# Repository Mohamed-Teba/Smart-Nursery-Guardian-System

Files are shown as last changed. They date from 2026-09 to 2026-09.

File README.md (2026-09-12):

# 🍼 Smart Nursery Guardian System

<p align="center">
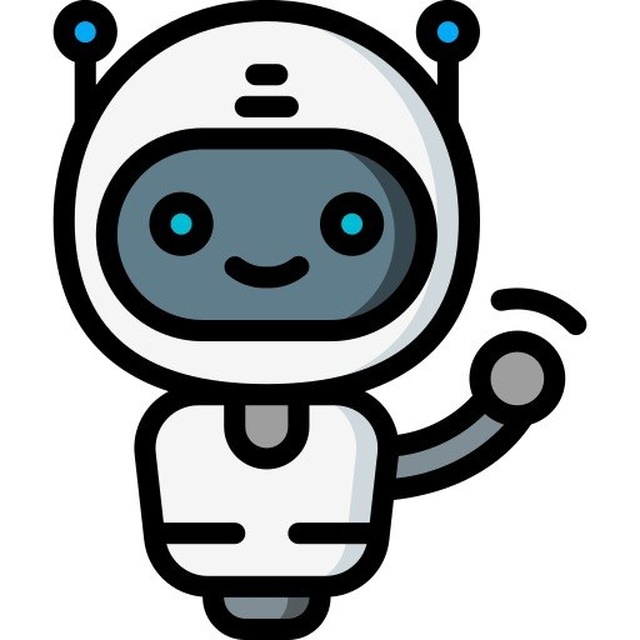
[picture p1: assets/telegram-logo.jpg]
Smart Nursery Guardian Logo
  
</p>

<p align="center">
  <strong>An intelligent IoT + Machine Learning system that monitors a baby’s environment, detects cry reasons, and alerts caregivers in real time.</strong>
</p>

<p align="center">
  
  
  
  
  
  
</p>

---

## 👥 Team 6 Members

| Name | ID |
|---|---|
| Mohamed Ibrahim | 7131E  |
| Pilopateer Hani | 7129E  |
| Tharaa Mohamed | 7005E  |

---

## 📖 Project Overview

**Smart Nursery Guardian** is a complete end-to-end smart baby monitoring system that combines:

- **Hardware sensors** (temperature, gas/smoke, light, motion)
- **Actuators** (fan, RGB LED, room lamp, servo rocker, buzzer)
- **Machine Learning** cry classification (Hungry / Tired / Discomfort)
- **Real-time dashboard** (Streamlit)
- **Instant caregiver alerts** via Telegram Bot

The system continuously monitors the nursery environment. When the baby cries, an audio clip is analyzed by a trained ML model. The predicted reason is sent to the Arduino, which activates the appropriate actuators, updates the LCD, and triggers a Telegram notification to the parents.

---

## ✨ Key Features

### 🔊 Cry Classification (ML)
- Detects three cry types: **Hungry**, **Tired**, **Discomfort**
- Feature extraction using Librosa (MFCC, spectral features, RMS, ZCR, etc.)
- Trained on the Donate-a-Cry corpus features dataset
- Real-time prediction from uploaded audio or live microphone

### 🌡️ Environmental Monitoring
- Temperature sensing + automatic fan speed control (Low / Half / Full)
- Gas / Smoke detection with emergency alert
- Light (LDR) sensing for automatic night lamp
- PIR motion detection to determine if baby is awake or sleeping

### 🤖 Smart Actuators
- **Servo motor** rocks the bed when baby is crying or awake
- **Buzzer** activates on Tired cry or Gas alert
- **RGB LED** indicates temperature status
- **Room lamp** turns on automatically in dark conditions when baby is active

### 📱 Caregiver Notifications
- Telegram Bot (`@SMART_NURSERY_GUARDIAN_bot`) sends instant alerts:
  - Cry reason + confidence
  - Gas / Smoke emergency

### 🖥️ Live Dashboard
- Beautiful dark-themed Streamlit interface
- Real-time metrics (Temp, Motion, Gas, Lamp)
- Serial log, ML info, mock testing buttons
- Manual audio upload for prediction

---

## 🖼️ System Screenshots

### Dashboard – Temp Alert
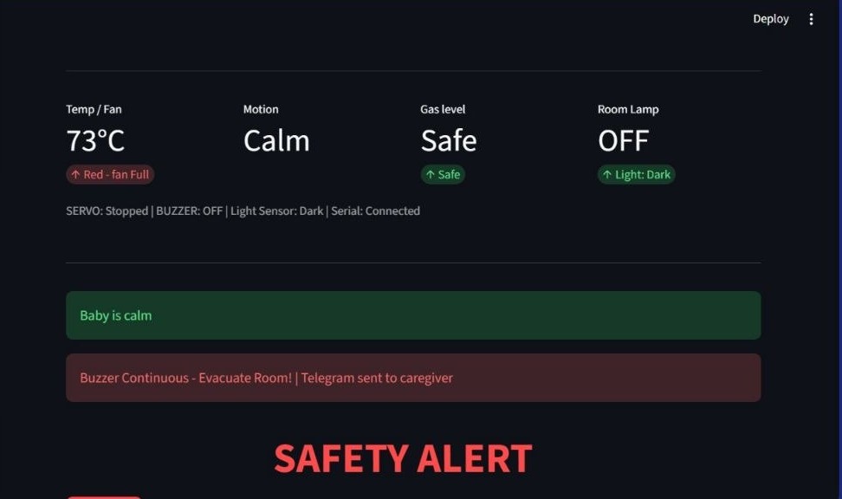
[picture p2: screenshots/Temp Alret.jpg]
Temp Alert Dashboard


### Dashboard – Gas Alert
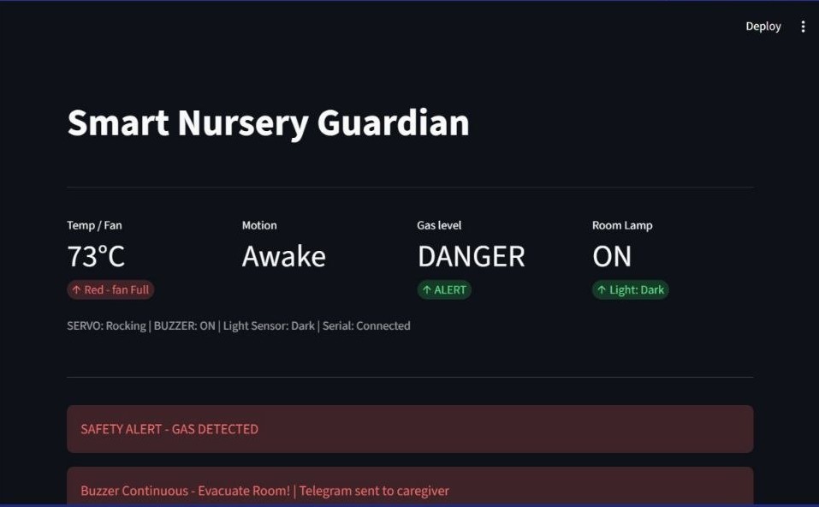
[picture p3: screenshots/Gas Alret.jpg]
Gas Alert Dashboard


### Hardware LCD Display
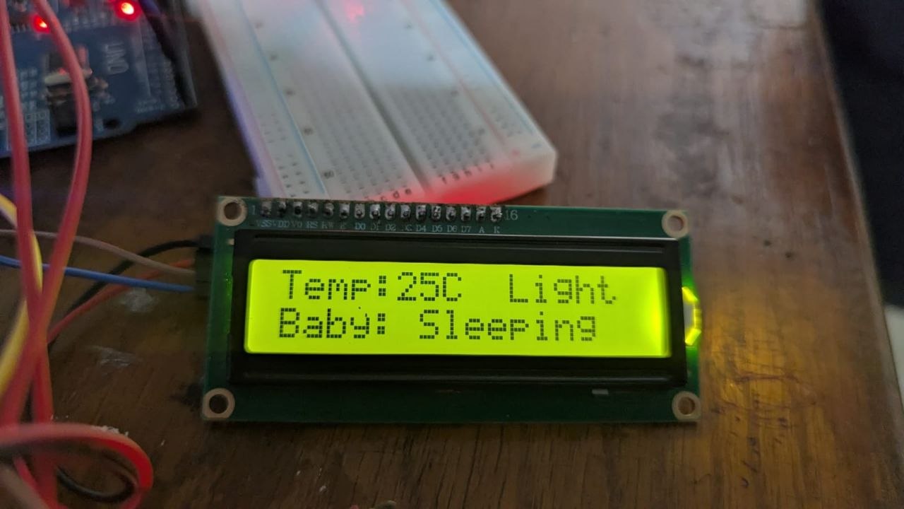
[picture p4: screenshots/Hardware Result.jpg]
Hardware LCD


### Telegram Bot
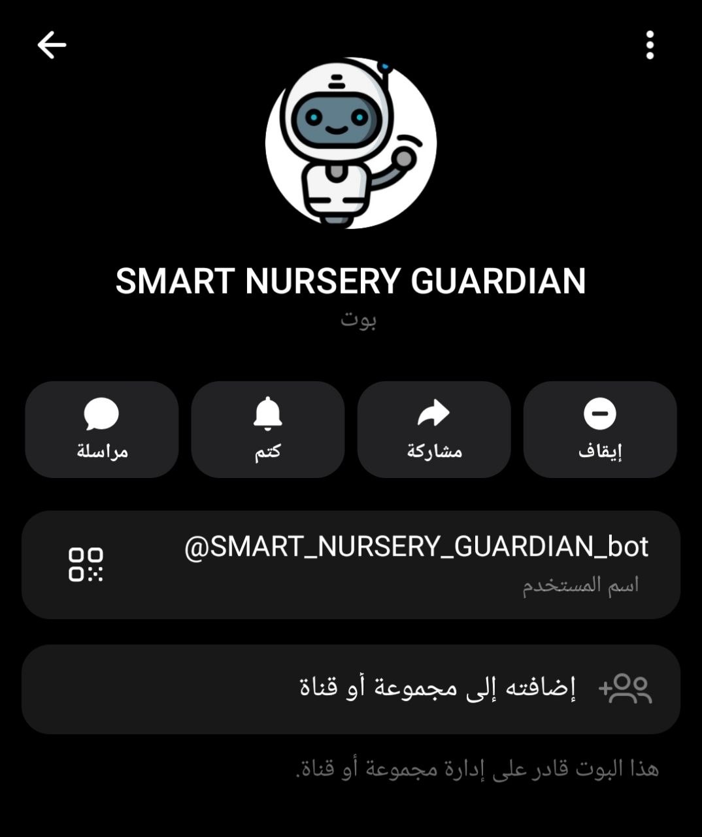
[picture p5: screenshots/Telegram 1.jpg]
Telegram Bot


---

## 🔌 Hardware Design

### Full Circuit Diagram
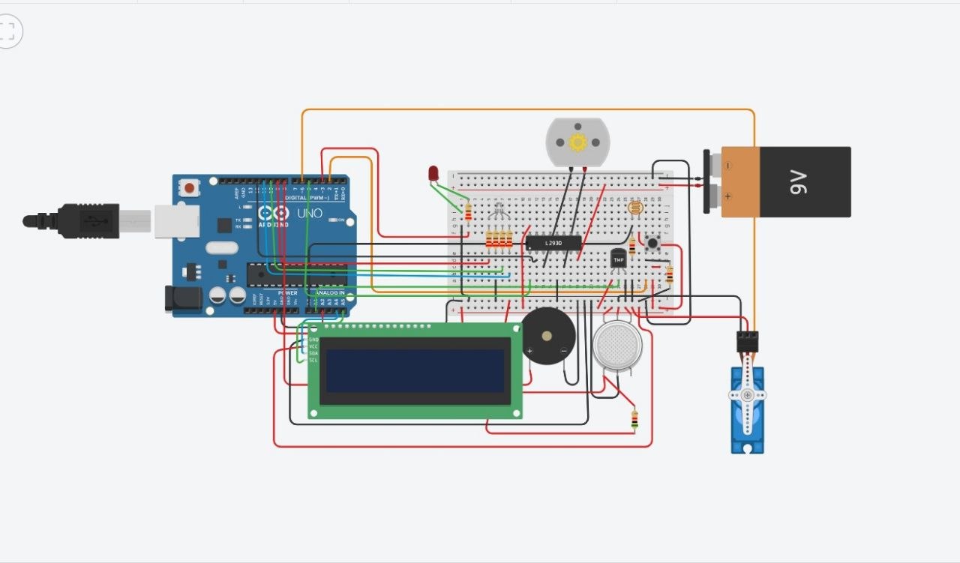
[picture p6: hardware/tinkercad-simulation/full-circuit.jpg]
Full Circuit


### Custom PCB (3D View)
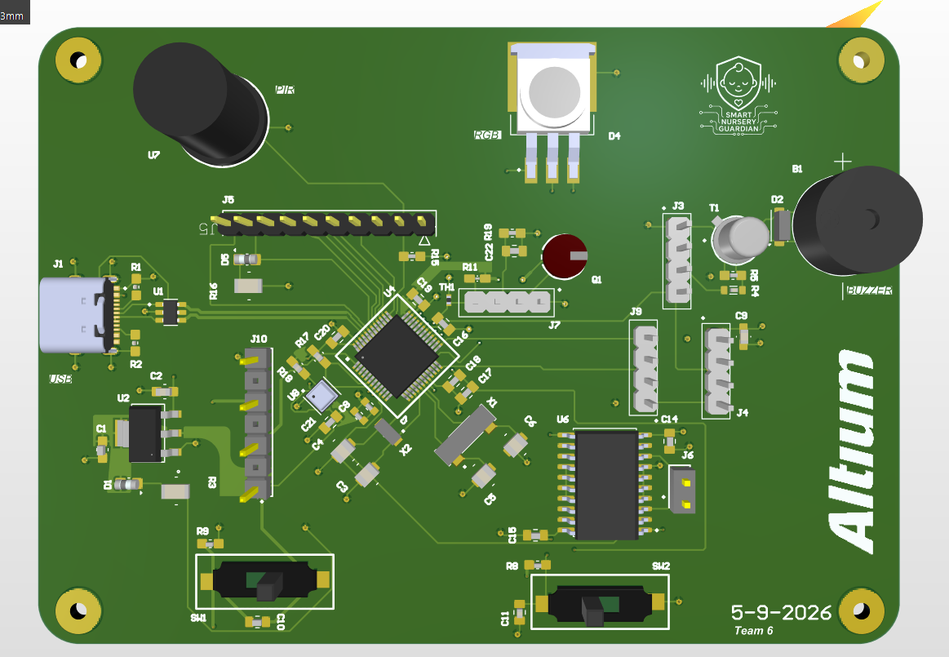
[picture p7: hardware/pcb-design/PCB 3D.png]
PCB 3D


> Designed in **Altium Designer** – dated 5-9-2026 – Team 6

### Main Components

| Component | Purpose | Pin / Connection |
|---|---|---|
| Arduino Uno | Main controller | - |
| LCD 16x2 (I2C) | Status display | SDA/SCL |
| PIR Motion Sensor | Detect baby movement | Digital 2 |
| LDR | Light intensity | Analog A0 |
| Temperature Sensor | Ambient temperature | Analog A1 |
| MQ Gas Sensor | Smoke / Gas detection | Analog A2 |
| Servo Motor | Rock the baby bed | Digital 6 |
| Buzzer | Audio alerts | Digital 8 |
| RGB LED | Temperature status indication | 9, 10, 11 |
| DC Fan + L293D | Cooling system | PWM 5 + Direction 12  |
| Room LED | Night lamp | Digital 3 |
| 9V Battery | External power for motor driver | - |

---

## 🧠 Machine Learning Pipeline

The model was trained on the **Donate-a-Cry Corpus Features Dataset**.

**Classes:**
- `hungry`
- `tired`
- `discomfort`

**Pipeline steps:**
1. Robust imputation + scaling
2. Feature selection (`SelectKBest`)
3. Class balancing (SMOTE / RandomOverSampler)
4. Model comparison (Logistic Regression, SVM, Random Forest, Extra Trees, HistGradientBoosting, KNN)
5. Hyperparameter tuning with `RandomizedSearchCV`
6. Final best model saved as `smart-nursery-guardian-model.pkl`

**Feature set (must match exactly at inference):**
- Amplitude_Envelope_Mean, RMS_Mean, ZCR_Mean, STFT_Mean
- SC_Mean, SBAN_Mean, SCON_Mean
- MFCCs13Mean, delMFCCs13, del2MFCCs13, MelSpec, MFCCs20
- MFCCs1 … MFCCs13

> See `machine-learning-pipeline.ipynb` for the complete training notebook.

---

## 🛠️ Software Architecture

```
┌─────────────────────┐       Serial (9600)      ┌─────────────────────┐
│  Streamlit Dashboard│ ◄──────────────────────► │   Arduino Firmware  │
│  (app.py)           │                          │   (main.ino)        │
│                     │                          │                     │
│  • ML Inference     │                          │  • Sensors reading  │
│  • Telegram Alerts  │                          │  • Actuator control │
│  • Live Metrics     │                          │  • LCD updates      │
│  • Serial Bridge    │                          │  • Command ACK      │
└─────────────────────┘                          └─────────────────────┘
```

**Communication Protocol**

| Direction | Message Example | Meaning |
|---|---|---|
| Laptop → Micro  | `CRY:hungry` | Activate hungry cry response |
| Laptop → Micro  | `CRY:tired` | Activate tired cry + buzzer |
| Laptop → Micro  | `CRY:discomfort` | Activate discomfort response |
| Laptop → Micro  | `RESET` | Return to calm state |
| Micro → Laptop  | `GAS:450` | Gas sensor value |
| Micro → Laptop  | `TEMP:28` | Temperature reading |
| Micro → Laptop  | `LIGHT:DARK` / `BRIGHT` | Light condition |
| Micro → Laptop  | `AWAKE` / `MOTION:3` | Motion / awake status |
| Micro → Laptop  | `ALERT:GAS_DETECTED` | Emergency gas alert |
| Micro → Laptop  | `ACK:CRY:Hungry` | Command acknowledgment |

---

## 🚀 Getting Started

### 1. Hardware Setup
1. Wire the circuit according to the diagram above (or use the custom PCB).
2. Upload `main.ino` to the Arduino Uno using the Arduino IDE.
3. Connect the Arduino to the laptop via USB.

### 2. Software Setup

```bash
# Clone the repository
git clone https://github.com/YOUR_USERNAME/smart-nursery-guardian.git
cd smart-nursery-guardian

# Create virtual environment (recommended)
python -m venv venv
source venv/bin/activate          # Windows: venv\Scripts\activate

# Install dependencies
pip install -r requirements.txt
```

**Required packages** (suggested `requirements.txt`):
```
streamlit
pyserial
joblib
numpy
pandas
scikit-learn
imbalanced-learn
librosa
sounddevice
soundfile
python-telegram-bot
```

### 3. Model Placement
Place the trained model file at:
```
model/smart-nursery-guardian-model.pkl
```

### 4. Telegram Configuration
Create a `.streamlit/secrets.toml` file:
```toml
Token = "YOUR_TELEGRAM_BOT_TOKEN"
chat_id = "YOUR_CHAT_ID"
```

### 5. Run the Dashboard
```bash
streamlit run app.py
```

---

## 🎮 How to Use

1. Open the Streamlit dashboard.
2. Enter the correct **COM Port** (e.g. `COM7` on Windows or `/dev/ttyUSB0` on Linux).
3. Click **Start Monitoring**.
4. Use the **Mock Tests** buttons to simulate cry types and gas alerts.
5. Upload a real cry audio file (WAV/MP3) and click **Predict Uploaded File**.
6. Watch the dashboard, LCD, actuators, and Telegram notifications update in real time.
7. Click **Reset** to return the system to calm state.

---

## 📁 Repository Structure

```
smart-nursery-guardian/
├── app.py                          # Streamlit dashboard + serial + ML + Telegram
├── main.ino                        # Arduino firmware
├── machine-learning-pipeline.ipynb # Full ML training notebook
├── model/
│   └── smart-nursery-guardian-model.pkl
├── assets/
│   ├── full-circuit.jpg
│   ├── PCB 3D.png
│   ├── Hardware Result.jpg
│   ├── Gas Alret.jpg
│   ├── Temp Alret.jpg
│   ├── Telegram 1.jpg
│   └── logo.png                    # (add your logo here)
├── requirements.txt
└── README.md
```

---

## 🔮 Future Improvements

- Continuous live microphone monitoring with background thread
- Edge deployment of the ML model on a Raspberry Pi / ESP32
- Mobile companion app
- Multi-baby support
- Historical data logging & analytics dashboard
- Better noise-robust cry detection

---

## 📄 License

This project was developed as an academic graduation / course project by **Team 6**.  
Feel free to use and modify it for educational purposes.

---

<p align="center">
  <strong>Made with ❤️ by Team 6 – Smart Nursery Guardian</strong><br>
  Protecting little ones with technology.
</p>

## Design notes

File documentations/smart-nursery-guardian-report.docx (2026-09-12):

SMART NURSERY GUARDIAN

An AI-Assisted Embedded Monitoring System for Infant Care

Final Project Report

Team 6

Name | ID | Role
Mohamed Ibrahim | 7131E | Machine Learning / Audio Pipeline / GUI / Telegram
Filopateer Hani | 7129E | Hardware / Serial Integration
Tharaa Mohamed | 7005E | PCB / Firmware

An intelligent crib-side system that listens to infant cries, classifies the cause

using machine learning, and automatically soothes the baby while notifying caregivers.

# Table of Contents:

1. Introduction ------------------------------------------------------------------------------------------------ 3

2. Project Objectives --------------------------------------------------------------------------------------- 3

3. System Overview & Architecture -------------------------------------------------------------------- 4

4. Hardware Design ----------------------------------------------------------------------------------------- 4

5. Software Design ------------------------------------------------------------------------------------------ 6

5.1 Streamlit Dashboard (Laptop)

5.2 Arduino Firmware (Microcontroller)

5.3 Serial Communication Protocol

6. Machine Learning Pipeline ----------------------------------------------------------------------------- 8

7. System Workflow (End-to-End) ----------------------------------------------------------------------- 9

8. Implementation Details & Screenshots ------------------------------------------------------------- 9

9. Testing & Results --------------------------------------------------------------------------------------- 11

10. Challenges & Solutions ------------------------------------------------------------------------------- 11

11. Conclusion ----------------------------------------------------------------------------------------------- 12

12. Future Work ----------------------------------------------------------------------------------------------12

13. Resources & References ----------------------------------------------------------------------------- 12

# 1. Introduction:

At 3 a.m., a baby cries. Is she hungry? Tired? In discomfort? The parent stands in darkness guessing. Crying is the infant’s only language, and most parents cannot read it fluently. Sleep deprivation, anxiety, and delayed responses are common consequences.

Smart Nursery Guardian is an AI-assisted embedded monitoring system that listens to the cry, uses a trained machine-learning model to identify the cause (hungry, tired, or discomfort), and reacts instantly: rocking the crib, displaying a clear message on an LCD and a modern GUI, sounding a buzzer when needed, and sending a Telegram alert to the caregiver’s phone. Nearby sensors continuously monitor motion, light level, air quality, and temperature, controlling lights and cooling automatically.

The system aims to respond as fast and attentively as a caregiver watching the crib — but never sleeps and never misses a signal.

## 1.1 Why This Project Matters

- Addresses a real, universal problem: sleep loss and stress caused by misinterpreting infant cries.
- Demonstrates a realistic technical stack: signal processing, classical ML, real-time firmware, GUI design, serial IoT communication, and cloud messaging.
- Bridges the gap between academic prototypes and practical home-use systems.

# 2. Project Objectives:

# | Objective | Success Criterion

1 | Classify infant cries into 3 clinically meaningful classes | Macro-F1 ≥ 0.75 on held-out test set
2 | Provide real-time visual & audible feedback | LCD + Streamlit GUI update < 1 s after prediction
3 | Automatically soothe the baby | Servo rocks continuously while cry is active
4 | Detect dangerous gas / smoke | Buzzer + Telegram alert within 2 s of threshold breach
5 | Maintain comfortable environment | Fan & RGB LED respond to temperature bands
6 | Notify caregiver remotely | Telegram message delivered for every cry & gas event

Cry Class | System Response | Priority
Hungry | Display message on GUI/LCD and play a calming video clip | Normal
Tired | Sound the buzzer immediately and display a warning (urgent pattern) | High
Discomfort | Display message and suggest checking diaper / clothing / position | Normal

# 3. System Overview & Architecture:

Two programs run on two devices and communicate over a serial (USB) link:

Component | Runs On | Main Responsibilities
Python / Streamlit App | Laptop | Microphone capture, feature extraction, ML inference, GUI dashboard, Telegram alerts, serial command & telemetry
Arduino Firmware | Microcontroller | Read PIR, LDR, thermistor, gas sensor; control servo, buzzer, room LED, RGB status LEDs, cooling fan; send sensor telemetry

## 3.1 Critical Data Paths

- Audio path (zero latency): Laptop microphone → Python feature extractor → trained model. Audio never crosses the serial link.
- Sensor path: Microcontroller reads sensors and streams values (GAS, TEMP, LIGHT, MOTION) to the laptop every second. Commands (CRY:hungry, RESET …) travel in the opposite direction.

This asymmetry is intentional: cry detection has the lowest possible latency, while environmental sensors can tolerate a short serial delay.

# 4. Hardware Design:

## 4.1 Bill of Materials & Pin Mapping

Component | Arduino Pin | Function
PIR Motion Sensor | D2 | Detect baby movement (awake detection)
LDR (Light Sensor) | A0 | Room darkness threshold
Thermistor (Temp) | A1 | Ambient temperature
MQ-series Gas Sensor | A2 | Smoke / gas detection
Room LED (Lamp) | D3 | Night light when dark + awake/cry
RGB LED – Red | D9 | Hot temperature indicator
RGB LED – Green | D10 | Comfortable temperature
RGB LED – Blue | D11 | Cold temperature
Cooling Fan (PWM) | D5 | Speed controlled by temperature
Fan Direction (IN) | D12 | Motor driver enable
Buzzer | D8 | Gas alert or tired-cry continuous tone
Servo Motor | D6 | Crib rocking (0° ↔ 90° ↔ 180°)
LCD 16×2 (I2C) | 0x27 | Local status display

## 4.2 Key Thresholds & Control Logic

Parameter | Value | Action
Darkness (LDR) | < 900 | Room considered dark
Gas / Smoke | > 400 | Buzzer ON + Telegram + GUI alert
Motion window | 8 seconds | Count PIR edges
Awake threshold | ≥ 4 motions | isBabyAwake = true
Temp < 25 °C | Blue LED | Fan low (PWM 100)
25–30 °C | Green LED | Fan half (PWM 160)
Temp > 30 °C | Red LED | Fan full (PWM 255)

## 4.3 Custom PCB Design

A custom 2-layer PCB was designed in Altium Designer (dated 5-9-2026, Team 6). The board integrates the microcontroller, sensor connectors, power regulation, servo and fan drivers, and the Smart Nursery Guardian logo.

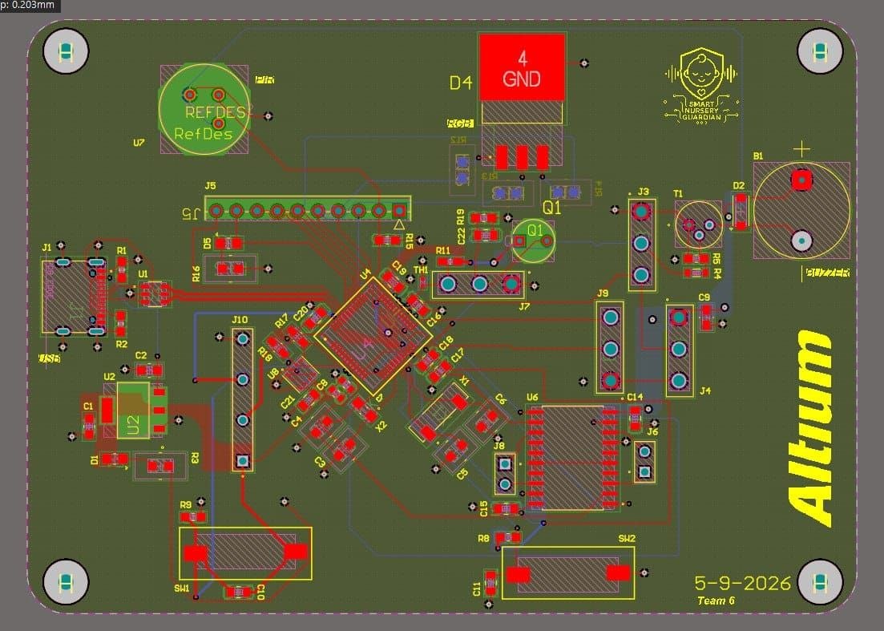
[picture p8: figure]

Figure 1 – PCB Layout (Altium Designer)

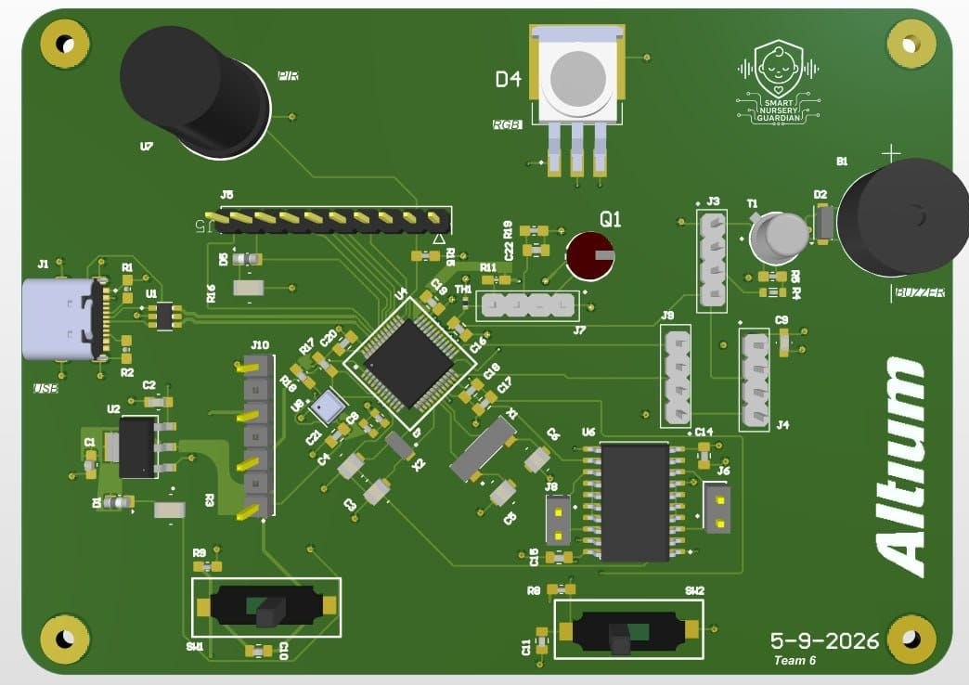
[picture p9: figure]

Figure 2 – 3D Render of the Assembled PCB

## 4.4 Hardware Prototype in Action


Figure 3 – Live LCD showing “Temp:25C Light / Baby: Sleeping” with surrounding sensors and wiring

5. Software Design:

## 5.1 Streamlit Dashboard (Laptop Side)

The caregiver interface is a responsive Streamlit web application that runs on the laptop. It provides real-time status cards, a serial log, manual audio upload, mock-test buttons, and automatic microphone monitoring.

Main Features

- Live metrics: Temperature / Fan, Motion (Awake/Calm), Gas level, Room Lamp
- Cry classification results with confidence scores
- Auto-mode continuous microphone loop (optional)
- Manual upload of cry audio files (WAV, MP3, …)
- Telegram notifications for every cry and gas event

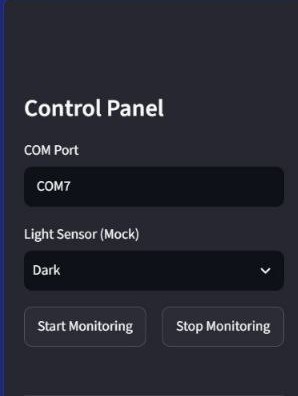
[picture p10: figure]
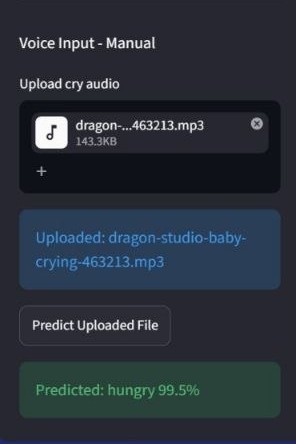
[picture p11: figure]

Figure 4 – Control Panel (COM Port & Start/Stop Monitoring) Figure 5 – Manual Voice Upload & Prediction Result (hungry 99.5%)

## 5.2 Arduino Firmware

The firmware (finalCodeHardware.ino) runs a tight non-blocking loop that:

- Reads serial commands from the laptop (CRY:hungry / tired / discomfort, RESET, …)
- Samples all sensors
- Updates the 8-second motion window and awake state
- Sends periodic telemetry (GAS, TEMP, LIGHT)
- Controls lighting, temperature actuators, buzzer, and servo rocking
- Refreshes the 16×2 LCD every 300 ms

## 5.3 Serial Communication Protocol

Direction | Message | Meaning
Laptop → MCU | CRY:hungry | Start hungry response (rock + display)
Laptop → MCU | CRY:tired | Start tired response (rock + continuous buzzer)
Laptop → MCU | CRY:discomfort | Start discomfort response
Laptop → MCU | RESET / CRY:END | Clear cry state, stop buzzer, center servo
MCU → Laptop | GAS:<value> | Raw gas sensor reading
MCU → Laptop | TEMP:<value> | Temperature in °C
MCU → Laptop | LIGHT:DARK/BRIGHT | Room light state
MCU → Laptop | MOTION:<n> | Motion count inside current window
MCU → Laptop | AWAKE | Baby declared awake (≥4 motions)
MCU → Laptop | ALERT:GAS_DETECTED | Gas threshold crossed
MCU → Laptop | ACK:… | Command acknowledgement

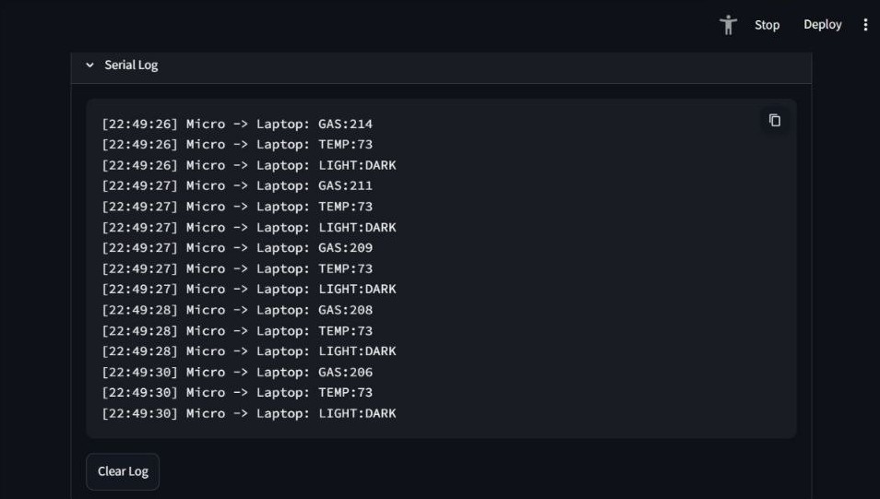
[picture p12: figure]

Figure 6 – Live Serial Log showing continuous GAS / TEMP / LIGHT telemetry

# 6. Machine Learning Pipeline:

## 6.1 Dataset

We used the publicly available Donate-a-Cry Corpus (457 labeled recordings). A pre-extracted feature version was obtained from Kaggle for rapid prototyping, while a matching feature-extraction routine was also implemented for live inference.

Class | Recordings | Percentage | System Response
Hungry | 382 | ≈ 84 % | Display message + optional calming video
Discomfort | 27 | ≈ 6 % | Display message (check diaper / position)
Tired | 24 | ≈ 5 % | Continuous buzzer + urgent warning

Note: The strong class imbalance is a well-known challenge of this dataset. SMOTE / RandomOverSampler inside the cross-validation pipeline and careful macro-F1 evaluation were used to mitigate it.

## 6.2 Feature Set (25 acoustic features)

Feature Group | Examples
Amplitude / Energy | Amplitude_Envelope_Mean, RMS_Mean
Temporal | ZCR_Mean
Spectral | STFT_Mean, SC_Mean, SBAN_Mean, SCON_Mean, MelSpec
MFCC | MFCCs13Mean, MFCCs1 … MFCCs13, MFCCs20
Delta MFCC | delMFCCs13, del2MFCCs13

## 6.3 Training Strategy

- 80 / 20 stratified train-test split (random_state = 42)
- 5-fold Stratified Cross-Validation inside the training set
- Pipeline: Imputer → Scaler → (optional) SMOTE → Classifier
- Models evaluated: Logistic Regression, SVM, Random Forest, Extra Trees, HistGradientBoosting, KNN, VotingClassifier
- Selection criterion: highest CV macro-F1 (balanced performance across the three classes)
- Final artifact saved as a single joblib file containing pipeline, feature names, class names

## 6.4 Live Inference Path

When a new audio file (or microphone buffer) arrives, the same feature-extraction recipe is applied, the resulting vector is fed to the loaded pipeline, and the predicted label plus confidence are returned. The GUI then issues the corresponding serial command and Telegram notification.

# 7. System Workflow (End-to-End):

## 7.1 Cry Detection & Classification

1. Laptop microphone (or uploaded file) captures audio.
1. Optional spectral noise reduction + voice-activity detection.
2. Fixed-length (5 s) feature vector is extracted.
3. Trained model returns one of {hungry, tired, discomfort} + confidence.
4. Streamlit updates status cards and log.
5. Serial command CRY:<label> is sent to the microcontroller.
6. Telegram message is dispatched to the caregiver.

## 7.2 Hardware Reaction

- Servo immediately begins a continuous rocking cycle (0° → 90° → 180°).
- LCD shows “Baby Crying! Reason: <label>”.
- If the label is tired, the buzzer stays on continuously.
- Room lamp turns on if the room is dark.

## 7.3 Environmental & Safety Loops

- PIR motion window (8 s) decides whether the baby is awake.
- Temperature band drives RGB LED colour and fan PWM.
- Gas sensor continuously compared against threshold 400; on breach the system enters the highest-priority SAFETY ALERT state (buzzer + full-screen GUI + Telegram).

# 8. Implementation Details & Screenshots

## 8.1 Gas Safety Alert (Highest Priority)


Figure 7 – GUI in SAFETY ALERT state: Gas = DANGER, Servo rocking, Buzzer ON, Telegram sent

## 8.2 Temperature / Calm State


Figure 8 – High temperature (73 °C in test) with Red-fan-Full indicator; baby calm

## 8.3 Telegram Bot Integration

A dedicated Telegram bot (@SMART_NURSERY_GUARDIAN_bot) receives every cry classification and every gas alert, giving the caregiver immediate mobile visibility even when away from the laptop. When gas is detected (or a cry is classified), the system sends a Telegram message to a pre-configured chat so the caregiver gets a phone alert even from another room. Implementation: a bot created through @BotFather provides the API token; the chat ID is read from the first getUpdates response; alerts are sent with python-telegram-bot — free, serverless, and far more reliable than browser-automation alternatives. Cry alerts are deduplicated per label and gas alerts are rate-limited to one message every 30 seconds to avoid notification spam.

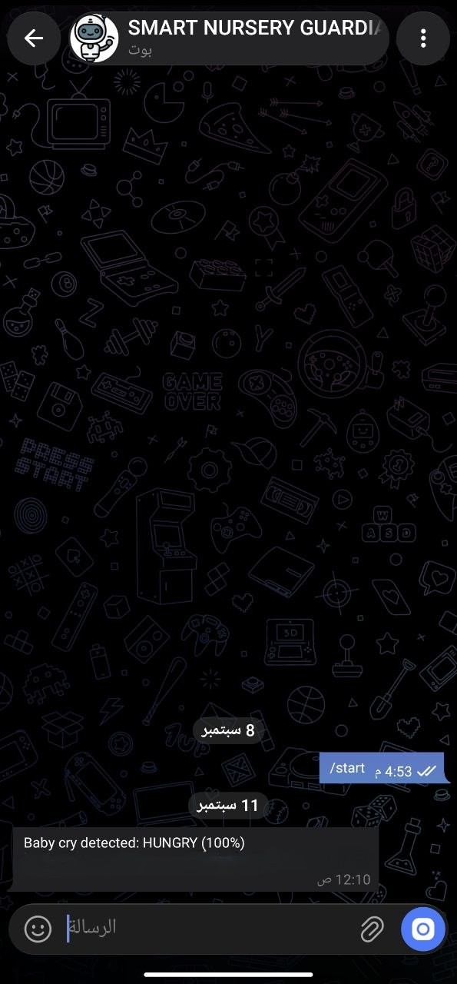
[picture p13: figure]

Figure 9 – Telegram bot profile Figure 10 – Real-time cry notification: “Baby cry detected: HUNGRY (100%)”

# 9. Testing & Results:

## 9.1 Functional Test Matrix

Test Case | Input / Stimulus | Expected Outcome | Result
Hungry cry (upload) | Audio file labelled hungry | GUI “hungry”, CRY:hungry, Telegram | Pass
Tired cry (mock) | Sidebar “Try Tired” | Continuous buzzer + LCD “Tired” | Pass
Discomfort cry | Sidebar “Try Discomfort” | LCD message + rock, no buzzer | Pass
Gas threshold | Sensor > 400 or mock button | Full SAFETY ALERT + Telegram | Pass
Motion → Awake | ≥ 4 PIR edges in 8 s | isBabyAwake, LCD “Awake” | Pass
Dark + Awake → Lamp | LDR dark + awake/cry | Room LED ON | Pass
Temperature bands | Thermistor readings | Correct RGB + fan PWM | Pass
Reset command | RESET / Clear button | All actuators return to idle | Pass
Serial telemetry | Continuous monitoring | GAS/TEMP/LIGHT every ≈1 s | Pass

## 9.2 Machine-Learning Evaluation Notes

Because of the severe class imbalance, overall accuracy alone is misleading. The final model was selected on the basis of macro-averaged F1 and balanced accuracy obtained from stratified 5-fold cross-validation. The saved artifact (smart_nursery_guardian_3class_best_model.pkl) contains the complete scikit-learn / imbalanced-learn pipeline and can be loaded once at GUI start-up for all subsequent inferences.

# 10. Challenges & Solutions:

Challenge | Solution Adopted
Severe class imbalance (hungry ≈ 84 %) | SMOTE / RandomOverSampler inside CV pipeline; selection by macro-F1 instead of accuracy
Feature schema mismatch risk | Strict feature-name validation before prediction; same extraction code used for training & live
Serial flooding / latency | 1-second telemetry throttle; non-blocking Arduino loop
False awake detections | 8-second sliding window + ≥ 4 motion edges required
Telegram spam | Per-label deduplication + 30-second rate limit on gas alerts
Streamlit thread-safety | Best-effort session-state updates from background mic thread; manual upload path remains fully synchronous

# 11. Conclusion:

Smart Nursery Guardian successfully demonstrates a complete, end-to-end intelligent infant-care system that combines classical machine learning, real-time embedded control, a modern web dashboard, and remote mobile notifications.

The three-class cry classifier, trained on the Donate-a-Cry corpus and carefully regularised against class imbalance, provides actionable guidance (hungry / tired / discomfort). The microcontroller reacts within milliseconds by rocking the crib, illuminating the room when needed, and raising an unmistakable safety alarm when gas is detected. Caregivers receive immediate Telegram messages and can monitor the entire system from a single Streamlit interface.

By splitting responsibilities — high-level AI and GUI on the laptop, low-level sensing and actuation on the microcontroller — the architecture mirrors professional IoT practice and remains maintainable and extensible. The project therefore fulfils both its technical and its human-centred goals: reducing parental uncertainty and improving the safety and comfort of the infant.

# 12. Future Work:

- Expand the cry taxonomy (pain, burping, environmental noise) with additional labelled data.
- Replace classical models with a lightweight spectrogram CNN or self-supervised audio encoder once more balanced data become available.
- Add on-device (edge) inference using TensorFlow Lite Micro or Edge Impulse for fully offline operation.
- Integrate a camera for visual confirmation of sleep posture and face occlusion.
- Multi-room / multi-crib support via MQTT or a local Wi-Fi mesh.
- Long-term data logging and parental insights dashboard (sleep patterns, cry frequency trends).
- Formal clinical validation study with paediatricians.

# 13. Resources & References:

## 13.1 Project Repositories & Media

- GitHub Repository: https://github.com/Mohamed-Teba/Smart-Nursery-Guardian-System

## 13.2 Datasets

- Infant Cry Audio Corpus – Kaggle: https://www.kaggle.com/datasets/warcoder/infant-cry-audio-corpus
- Pre-extracted Features – Kaggle: https://www.kaggle.com/datasets/bhoomikavalani/donateacrycorpusfeaturesdataset

## 13.3 Libraries & Frameworks

- Python 3.12, scikit-learn, imbalanced-learn, librosa, joblib
- Streamlit (GUI), pyserial, python-telegram-bot
- Arduino / AVR C++ (LiquidCrystal_I2C, Servo)
- Altium Designer (PCB)

## 13.4 Academic & Technical References

- G. Veres et al., “Donate-a-Cry Corpus” – public infant cry dataset used for training.
- Published studies on MFCC-based infant cry classification reporting >90 % accuracy after proper balancing and augmentation.
- scikit-learn documentation – Pipeline, StratifiedKFold, metrics.
- librosa documentation – feature extraction (MFCC, spectral, RMS, ZCR).
- Streamlit documentation – session state, caching, file upload.
- Arduino Reference – Servo, analogRead, Serial protocol design patterns.

Team 6 — Mohamed Ibrahim (7131E), Filopateer Hani (7129E), Tharaa Mohamed (7005E)

Smart Nursery Guardian — Final Project Documentation

Smart Nursery Guardian | Team 6 | Page 13

SMART NURSERY GUARDIAN — Final Project Documentation

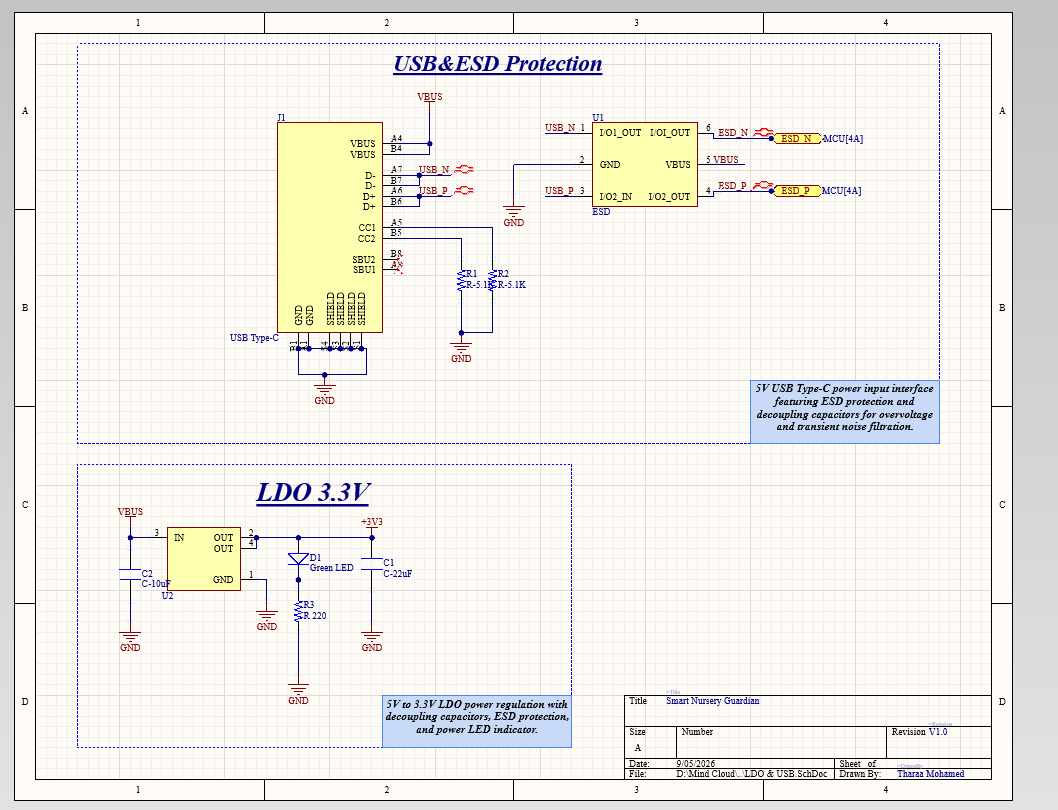
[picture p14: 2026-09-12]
hardware/pcb-design/LDO & USB SCH.png

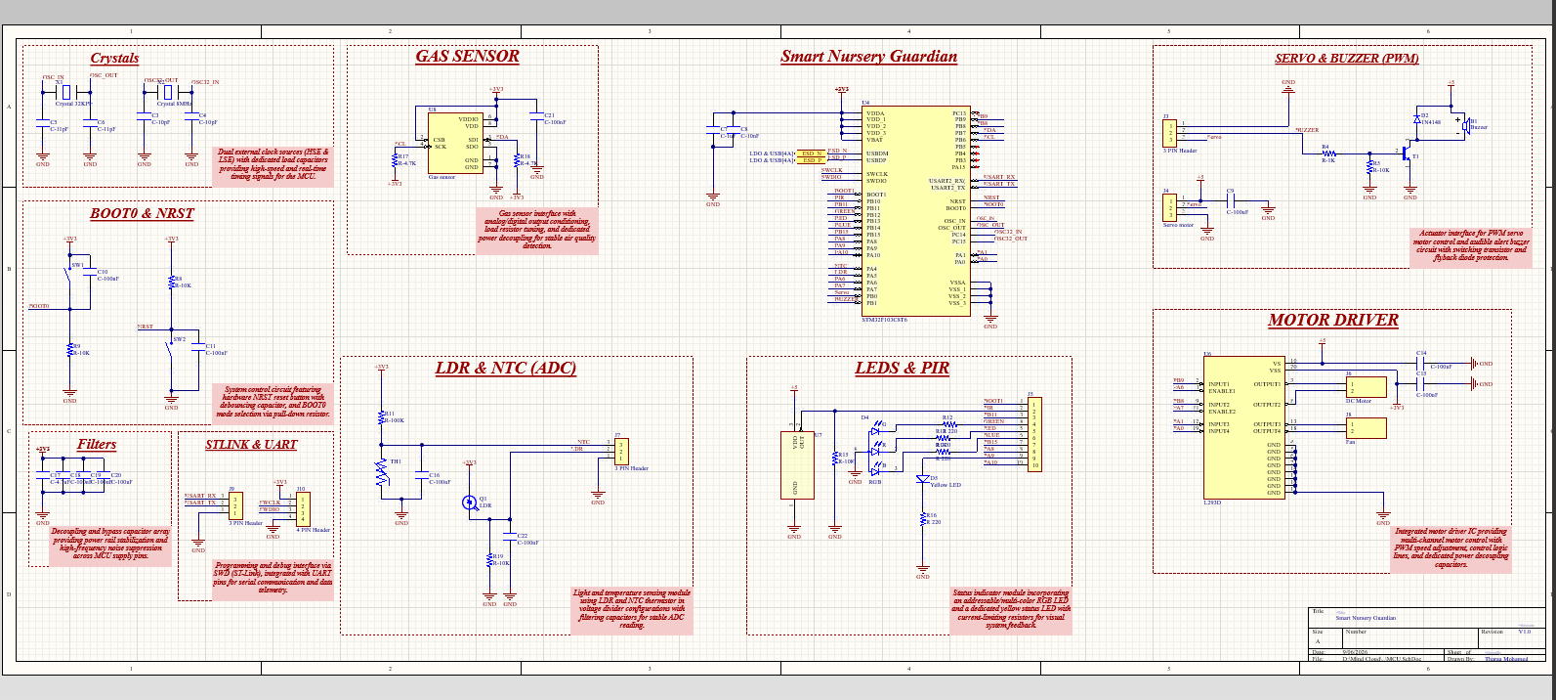
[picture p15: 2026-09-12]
hardware/pcb-design/SCH.png

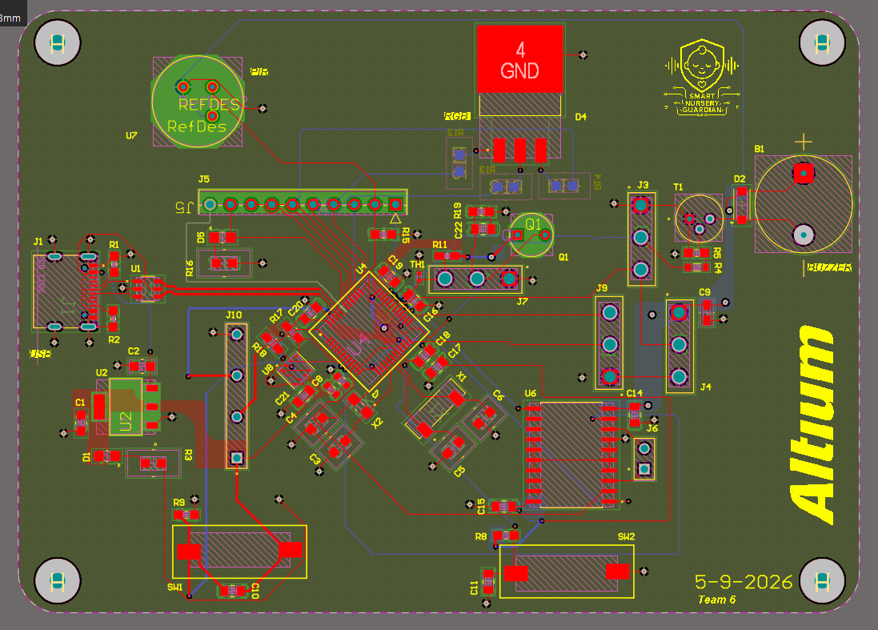
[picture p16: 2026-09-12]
hardware/pcb-design/PCB 2D.png

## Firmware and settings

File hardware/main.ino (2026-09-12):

#include <LiquidCrystal_I2C.h>
#include <Servo.h>

LiquidCrystal_I2C lcd(0x27, 16, 2);
Servo bedServo;

#define PIR_PIN     2
#define LDR_PIN     A0
#define TEMP_PIN    A1
#define ROOM_LED    3
#define RED         9
#define GREEN       10
#define BLUE        11
#define FAN_PIN     5
#define IN          12
#define GAS_PIN     A2
#define BUZZER_PIN  8
#define SERVO_PIN   6

const int DARKNESS_THRESHOLD = 500;
const int GAS_THRESHOLD      = 400;

// ---- Sensor state ----

int  pirState = LOW;
int  lastPirState = LOW;
int  motionCount = 0;
unsigned long windowStartTime = 0;
const unsigned long WINDOW_DURATION = 8000;
bool isBabyAwake = false;

int  ldrValue = 0;
bool roomDark = false;

float temp = 0.0;
float volt = 0.0;

int  gasValue = 0;
bool gasAlert = false;
bool lastGasState = false;

// ---- Commands from Python / ML ----

bool isCryDetected = false;
bool isTiredBuzzerOn = false;
String cryType = "None";

// ---- Timing ----

unsigned long lastLCDUpdate   = 0;
unsigned long lastServoMove   = 0;
unsigned long lastSensorPrint = 0;
int  servoState = 0;

String serialBuffer = "";

void setup() {
  pinMode(PIR_PIN, INPUT);
  pinMode(LDR_PIN, INPUT);
  pinMode(TEMP_PIN, INPUT);
  pinMode(ROOM_LED, OUTPUT);
  pinMode(RED, OUTPUT);
  pinMode(GREEN, OUTPUT);
  pinMode(BLUE, OUTPUT);
  pinMode(FAN_PIN, OUTPUT);
  pinMode(IN, OUTPUT);
  pinMode(GAS_PIN, INPUT);
  pinMode(BUZZER_PIN, OUTPUT);

  Serial.begin(9600);

  lcd.init();
  lcd.backlight();
  lcd.setCursor(0, 0);
  lcd.print("Smart Baby Bed");
  lcd.setCursor(0, 1);
  lcd.print("System Ready...");
  delay(1500);
  lcd.clear();

  bedServo.attach(SERVO_PIN);
  bedServo.write(90);

  Serial.println("READY");
}

// ============================================================
// Receive commands from Laptop (Streamlit + ML)
// ============================================================

void processSerialCommand(String cmd) {
  cmd.trim();
  cmd.toUpperCase();

  if (cmd == "CRY:END" || cmd == "RESET" || cmd == "CRY_END") {
    isCryDetected   = false;
    isTiredBuzzerOn = false;
    cryType         = "None";

    bedServo.write(90);
    Serial.println("ACK:RESET");
  }
  else if (cmd.startsWith("CRY:")) {
    String reason = cmd.substring(4);
    reason.trim();
    reason.toLowerCase();

    isCryDetected = true;
    isBabyAwake   = true;

    if (reason == "hungry") {
      cryType = "Hungry";
      isTiredBuzzerOn = false;
    } else if (reason == "tired") {
      cryType = "Tired";
      isTiredBuzzerOn = true;
    } else if (reason == "discomfort") {
      cryType = "Discomfort";
      isTiredBuzzerOn = false;
    } else {
      cryType = reason;
      isTiredBuzzerOn = false;
    }

    Serial.print("ACK:CRY:");
    Serial.println(cryType);
  }
  else if (cmd == "GAS_CLEARED") {
    Serial.println("ACK:GAS_CLEARED");
  }
}

void readSerialFromLaptop() {
  while (Serial.available() > 0) {
    char c = Serial.read();
    if (c == '\n' || c == '\r') {
      if (serialBuffer.length() > 0) {
        processSerialCommand(serialBuffer);
        serialBuffer = "";
      }
    } else {
      serialBuffer += c;
      if (serialBuffer.length() > 64) {
        serialBuffer = "";
      }
    }
  }
}

// ============================================================
// Sensors
// ============================================================

void readSensors() {
  pirState = digitalRead(PIR_PIN);
  ldrValue = analogRead(LDR_PIN);
  roomDark = (ldrValue > DARKNESS_THRESHOLD);

  volt = analogRead(TEMP_PIN);
  temp = (volt * 5.0 / 1024.0) * 100.0;

  gasValue = analogRead(GAS_PIN);
  gasAlert = (gasValue > GAS_THRESHOLD);
}

void updateMotion() {
  unsigned long currentTime = millis();

  if (currentTime - windowStartTime >= WINDOW_DURATION) {
    windowStartTime = currentTime;
    motionCount = 0;
    if (!isCryDetected) {
      isBabyAwake = false;
    }
  }

  if (pirState == HIGH && lastPirState == LOW) {
    motionCount++;
    Serial.print("MOTION:");
    Serial.println(motionCount);

    if (motionCount >= 4) {
      isBabyAwake = true;
      Serial.println("AWAKE");
    }
  }
  lastPirState = pirState;
}


void sendSensorTelemetry() {
  if (millis() - lastSensorPrint < 1000) return;
  lastSensorPrint = millis();

  Serial.print("GAS:");
  Serial.println(gasValue);

  Serial.print("TEMP:");
  Serial.println((int)temp);

  Serial.print("LIGHT:");
  Serial.println(roomDark ? "DARK" : "BRIGHT");
}

// ============================================================
// Actuators
// ============================================================

void handleLighting() {
  if (roomDark && (isBabyAwake || isCryDetected || gasAlert)) {
    digitalWrite(ROOM_LED, HIGH);
  } else {
    digitalWrite(ROOM_LED, LOW);
  }
}

void handleTemp() {
  if (temp < 25.0) {
    digitalWrite(RED, LOW);
    digitalWrite(GREEN, LOW);
    digitalWrite(BLUE, HIGH);
    analogWrite(FAN_PIN, 100);
    digitalWrite(IN, HIGH);
  } else if (temp <= 30.0) {
    digitalWrite(RED, LOW);
    digitalWrite(GREEN, HIGH);
    digitalWrite(BLUE, LOW);
    analogWrite(FAN_PIN, 160);
    digitalWrite(IN, HIGH);
  } else {
    digitalWrite(RED, HIGH);
    digitalWrite(GREEN, LOW);
    digitalWrite(BLUE, LOW);
    analogWrite(FAN_PIN, 255);
    digitalWrite(IN, HIGH);
  }
}

void handleSafetyAlerts() {
  if (gasAlert || isTiredBuzzerOn) {
    digitalWrite(BUZZER_PIN, HIGH);
  } else {
    digitalWrite(BUZZER_PIN, LOW);
  }

  if (gasAlert && !lastGasState) {
    Serial.println("ALERT:GAS_DETECTED");
  }
  lastGasState = gasAlert;
}

void handleServo() {
  if (isBabyAwake || isCryDetected || gasAlert) {
    unsigned long currentTime = millis();
    if (currentTime - lastServoMove >= 600) {
      lastServoMove = currentTime;
      if (servoState == 0) {
        bedServo.write(0);
        servoState = 1;
      } else if (servoState == 1) {
        bedServo.write(90);
        servoState = 2;
      } else {
        bedServo.write(180);
        servoState = 0;
      }
    }
  } else {
    bedServo.write(90);
    servoState = 0;
  }
}

void updateDisplay() {
  if (millis() - lastLCDUpdate < 300) return;
  lastLCDUpdate = millis();

  if (gasAlert) {
    lcd.clear();
    lcd.setCursor(0, 0);
    lcd.print("!! DANGER !!");
    lcd.setCursor(0, 1);
    lcd.print("GAS DETECTED!");
  } else if (isCryDetected) {
    lcd.clear();
    lcd.setCursor(0, 0);
    lcd.print("Baby Crying!");
    lcd.setCursor(0, 1);
    lcd.print("Reason: ");
    lcd.print(cryType);
  } else {
    lcd.setCursor(0, 0);
    lcd.print("Temp:");
    lcd.print((int)temp);
    lcd.print("C  ");
    lcd.print(roomDark ? "Dark " : "Light");

    lcd.setCursor(0, 1);
    lcd.print("Baby: ");
    lcd.print(isBabyAwake ? "Awake   " : "Sleeping");
  }
}

void loop() {
  readSerialFromLaptop();
  readSensors();
  updateMotion();
  sendSensorTelemetry();
  handleLighting();
  handleTemp();
  handleSafetyAlerts();
  handleServo();
  updateDisplay();
  delay(30);
}

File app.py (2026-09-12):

import streamlit as st
import os
import joblib
import tempfile
import threading
import time
import numpy as np
from datetime import datetime
from pathlib import Path

st.set_page_config(page_title="Smart Nursery Guardian System", layout="wide")
st.title("Smart Nursery Guardian System")
st.markdown("---")

# ---------------------------------------------------------------------------
# Session state
# ---------------------------------------------------------------------------

defaults = {
    "status": "calm",
    "temp": 26,
    "light": "Bright",
    "gas": "Safe",
    "is_awake": False,
    "log": [],
    "monitoring": False,
    "auto_mode": False,
    "last_prediction": "-",
    "auto_thread_running": False,
    "serial_port": None,
    "last_telegram_gas": 0.0,
    "last_telegram_cry": "",
}
for k, v in defaults.items():
    if k not in st.session_state:
        st.session_state[k] = v

def add_log(msg: str):
    ts = datetime.now().strftime("%H:%M:%S")
    st.session_state.log.append(f"[{ts}] {msg}")
    if len(st.session_state.log) > 40:
        st.session_state.log = st.session_state.log[-40:]

# ---------------------------------------------------------------------------
# Telegram
# ---------------------------------------------------------------------------

def _get_telegram_credentials():
    try:
        return st.secrets["Token"], st.secrets["chat_id"]
    except Exception:
        return None, None

async def _send_telegram_bot(token: str, chat_id: str, msg: str):
    from telegram import Bot
    bot = Bot(token=token)
    await bot.send_message(chat_id=chat_id, text=msg)

def send_telegram(msg: str, force: bool = False):
    """Send alert to caregiver. force=True skips dedup."""
    token, chat_id = _get_telegram_credentials()
    if not token or not chat_id:
        add_log("Telegram skipped: missing Token/chat_id in secrets")
        return False
    try:
        import asyncio
        asyncio.run(_send_telegram_bot(token, chat_id, msg))
        st.toast("Telegram Sent")
        add_log(f"Laptop -> Telegram: {msg}")
        return True
    except Exception as e:
        st.error(f"Telegram Failed: {e}")
        add_log(f"Telegram ERROR: {e}")
        return False

def notify_cry(label: str, confidence: float = 0.0, source: str = "ML", force: bool = False):
    """Telegram + log for cry predictions (dedup same label within session)."""
    key = f"{label}:{source}"
    if not force and st.session_state.last_telegram_cry == key:
        return
    conf_txt = f" ({confidence:.0%})" if confidence else ""
    msg = f"Your Baby is Crying. He is: {label.capitalize()}"
    if send_telegram(msg):
        st.session_state.last_telegram_cry = key

def notify_gas():
    """Telegram for gas (rate-limited to once per 30s)."""
    now = time.time()
    if now - st.session_state.last_telegram_gas < 30:
        return
    if send_telegram("GAS ALERT: Gas/Smoke Detected. Evacuate The Room Now"):
        st.session_state.last_telegram_gas = now


# ---------------------------------------------------------------------------
# Serial helpers (persistent connection while monitoring)
# ---------------------------------------------------------------------------

def open_serial(port: str, baud: int = 9600):
    try:
        import serial

        if not hasattr(serial, "Serial"):
            location = getattr(serial, "__file__", None)
            raise RuntimeError(
                "Invalid serial module loaded"
                f" ({location}). Install pyserial in the same Python environment."
            )

        if st.session_state.serial_port is not None:
            try:
                st.session_state.serial_port.close()
            except Exception:
                pass
            st.session_state.serial_port = None

        ser = serial.Serial(port=port, baudrate=baud, timeout=0.3)
        time.sleep(1.5)  # Arduino Uno/Nano may reset when the port opens.
        st.session_state.serial_port = ser
        add_log(f"Serial OPEN {port} @ {baud}")
        return ser
    except Exception as e:
        add_log(f"Serial open failed: {e}")
        st.session_state.serial_port = None
        return None

def close_serial():
    ser = st.session_state.serial_port
    if ser is not None:
        try:
            ser.close()
        except Exception:
            pass
    st.session_state.serial_port = None
    add_log("Serial CLOSED")

def serial_write(cmd: str):
    """Send a line command to Arduino (CRY:hungry, RESET, ...)."""
    ser = st.session_state.serial_port
    if ser is None or not ser.is_open:
        add_log(f"Serial WRITE skipped (not connected): {cmd}")
        return False
    try:
        line = (cmd.strip() + "\n").encode("utf-8")
        ser.write(line)
        ser.flush()
        add_log(f"Laptop -> Micro: {cmd}")
        return True
    except Exception as e:
        add_log(f"Serial WRITE error: {e}")
        return False

def apply_ml_action(label: str, confidence: float = 0.0, source: str = "ML"):
    """
    After ML prediction:
      1. Update GUI state
      2. Command Arduino actuators
      3. Notify Telegram
    """
    label = str(label).strip().lower()
    st.session_state.status = label
    st.session_state.is_awake = True
    conf = confidence or 0.0
    st.session_state.last_prediction = f"{label} ({conf:.1%}) [{source}]"

    if label in ("hungry", "tired", "discomfort"):
        serial_write(f"CRY:{label}")
        notify_cry(label, conf, source)
    elif label == "gas":
        st.session_state.gas = "DANGER"
        notify_gas()
    add_log(f"ML ACTION applied: {label}")

def reset_system():
    """Calm state + stop actuators on hardware."""
    serial_write("RESET")
    st.session_state.status = "calm"
    st.session_state.is_awake = False
    st.session_state.gas = "Safe"
    st.session_state.temp = 26
    st.session_state.last_telegram_cry = ""
    add_log("System RESET")

# ---------------------------------------------------------------------------
# ML model
# ---------------------------------------------------------------------------

@st.cache_resource
def load_model():
    candidates = [
        Path(r"model\smart-nursery-guardian-model.pkl")
    ]
    for p in candidates:
        if p.exists():
            try:
                art = joblib.load(p)
                required = {"pipeline", "feature_names", "class_names", "model_name"}
                missing = required - set(art.keys())
                if missing:
                    return None, f"Invalid artifact {p}: missing {missing}"
                return art, None
            except Exception as e:
                return None, f"Load failed {p}: {e}"
    return None, "Model not found. Place smart_nursery_guardian.pkl inside model/"

artifact, ml_error = load_model()
ml_ready = artifact is not None
if ml_error:
    st.warning(ml_error)
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
